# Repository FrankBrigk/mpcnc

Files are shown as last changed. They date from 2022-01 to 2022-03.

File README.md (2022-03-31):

# mpcnc
Dokumentation &amp; Austausch zum Communityprojekt MPCNC

## Bau einer Mostly Printed CNC

**Source**: [v1engineering.com](https://www.v1engineering.com)

**Mod**: Bauraum (X|Y|Z): 980 x 1500 x 81 mm

**Steuerung**: Estlcam V11 via Laptop

**Wunschkonzert**

- Absaugung
- Steuerboard
- SD-Karten/Wifi-Anbindung
- Spann-/Anschlagraster
- Trucks für X-Achse anpassen (Nut) um den Bauraum der Fräße zu vergrößern?

## Dokumentation Communitytreffen

**Total Working Hours: 166.75 | Pizzas: 35.5 | Slices: 284**

### 2022/03/29

**Facts**

Participants: 5  | Hours: 4.5  | Pizzas: 4

**TOPs**

- ~~Pizza~~

**ToDos**

- ~~Absaugung besprechen~~
- ~~Lochraster besprechen~~
- ~~Motorsteuerung~~
- ~~Tastplatte~~ eingerichtet
- ~~Notaus besprechen~~
- ~~Feintuning~~ Belts nachgebessert, Schrittverluste überprüft
- ~~Testfräsungen~~ erfolgreich in Styrodur gefräst

**Zum nächsten Termin**

### 2022/03/22

**Facts**

Participants: 5  | Hours: 3  | Pizzas: 4

**TOPs**

- ~~Pizza~~

**ToDos**

- ~~Z-Achse ansteuern~~
- ~~Testzeichnungen~~
- **~~Testfräsungen!!!!~~**

**Zum nächsten Termin**

### 2022/03/15

**Facts**

Participants: 3  | Hours: 3.5  | Pizzas: 2

**TOPs**

- ~~Pizza~~

**ToDos**

- ~~Drag Chain Halterungen nachbessern~~
- ~~Drag Chains und Halterungen installieren~~
- ~~Z-Achse anschließen~~

**Zum nächsten Termin**

### 2022/03/08

**Facts**

Participants: 5  | Hours: 4  | Pizzas: 5

**TOPs**

- ~~Pizza~~

**ToDos**

- ~~Einzug der Kabel~~
- ~~Drag Chain Halterungen planen und konstruieren~~
- ~~defekten Stepper-Driver tauschen~~
- ~~Probefahrt!~~

**Zum nächsten Termin**

### 2022/02/22

**Facts**

Participants: 4   | Hours: 4  | Pizzas: 3

**TOPs**

- ~~Pizza~~

**ToDos**

- ~~Ausrichtung X/Y diskutieren~~ bleibt wie bestehen wg. Einsehbarkeit Fräsfläche
- ~~Planung der Kabelführung~~
- Einzug der Kabel
- defekten Stepper-Driver tauschen
- ~~defekten Schlitten tauschen~~
- ~~Gt2 Belts einziehen~~
- ~~Mid-Span Supports einbauen~~
- ~~Schleppkette~~

**Zum nächsten Termin**

- Drag Chain (bestellt)

### 2022/02/15

**Facts**

Participants: 4   | Hours: 4  | Pizzas: 3

**TOPs**

- ~~Pizza~~

**ToDos**

- ~~Y-Adapter anfertigen~~
- ~~Werkzeug Halterung fertig verschrauben~~
- ~~Z Achse fertig montieren~~
- ~~rechtwinklig ausrichten~~

**Zum nächsten Termin**

- Planung der Kabelführung
- Gt2 Belts einziehen

### 2022/02/08

**Facts**

Participants: 3   | Hours:  3.5  | Pizzas: 2

**TOPs**

- Pizza

**ToDos**

- ~~Rohr Konstruktion fixieren~~
- ~~Achsen mobtieren~~
- ~~Beginn Z Achse Montage ~~
- ~~Elektronik verdrahten~~

**Zum nächsten Termin**

- Y-Adapter anfertigen
- Werkzeug Halterung fertig verschrauben
- Z Achse fertig montieren
- Planung der Kabelführung
- Gt2 Belts einziehen

### 2022/02/01

**Facts**

Participants: 7  | Hours: 3.5   | Pizzas: 6.5

**TOPs**

- ~~Pizza~~

**ToDos**

- ~~Päckchen auspacken~~
- ~~Montage fortsetzen~~
- ~~Opferplatte montieren~~
- ~~Z-Core fertig montieren~~
- ~~Gehäuse für Elektronik herstellen~~
- Y-Adapter anfertigen
- Elektronik verdrahten

**Zum nächsten Termin**

- fehlende Schrauben kaufen
- Eurokisten für Zubehör

### 2022/01/25

**Facts**

Participants: 6  | Hours: 3.5  | Pizzas: 5

**TOPs**

- ~~Pizza~~
- ~~Crimpzange prüfen und Dupontstecker bestellen ~~
- ~~Drag Chains? Make vs. buy~~ werden bei Bedarf selbst gedruckt
- ~~Mid rail supports?~~ dann
- ~~Hour & Pizza Count~~

**ToDos**

- ~~Workbench aufbauen~~
- ~~Rohre für Z-Achse kürzen~~
- ~~Montage Schlitten und Fräserhalterung~~
- ~~Roadmap/Milestones festlegen~~

**Zum nächsten Termin**

### 2022/01/18

**Facts**

Participants: 5 | Hours: 2.5 | Pizzas: 5

**TOPs**

Pizza
- ~~Druck in .3 Schichtdicke~~ abgelehnt wegen Konflikt Schichtdicken Prusa MK3S & Mini
- ~~Handling Github~~
- ~~kritisch: gewählte Z-Achsenlänge von 150mm~~ auf 81 mm Z-Zustellung geeinigt
- ~~Railsupports~~ werden nach Inbetriebnahme nach Bedarf erstellt
- ~~Kommunikationskanal~~ Gruppe im Messengerdienst Signal
- ~~Slicing & Druckaufteilung~~ gemäß Tabelle im Readme unter Druckdateien

**ToDos**

- ~~Unboxing~~
- Workbench aufbauen
- Elektronik testen
- Roadmap/Milestones festlegen

**Zum nächsten Termin**

- Tischplatte
- Styrodur

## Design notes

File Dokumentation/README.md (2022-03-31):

Die Dokumentationskaptiel wurden zunächst aus dem Standard Arc42 übernommen und müssen noch diskutiert werden. https://www.arc42.de/

**Inhaltsverzeichnis**

- [Einführung und Ziele](#einführung-und-ziele)
- [Randbedingungen](#randbedingungen)
- [Kontextabgrenzung](#kontextabgrenzung)
- [Lösungsstrategie](#lösungsstrategie)
  - [Bauraum](#bauraum)
- [Bausteinsicht](#bausteinsicht)
  - [Level 1 MPCNC](#level-1-mpcnc)
    - [Estlcam](#estlcam)
    - [Motoren](#motoren)
    - [Endschalter](#endschalter)
    - [Tastplatte](#tastplatte)
    - [Steuerung](#steuerung)
  - [Level 2 Steuerung](#level-2-steuerung)
  - [Level 3 CNC Shield](#level-3-cnc-shield)
    - [Pinout](#pinout)
- [Laufzeitsicht](#laufzeitsicht)
- [Verteilungssicht](#verteilungssicht)
- [Querschnittliche Konzepte](#querschnittliche-konzepte)
- [Entscheidungen](#entscheidungen)
  - [Endstops](#endstops)
  - [Ändern der Trucks](#ändern-der-trucks)
- [Qualitätsanforderungen](#qualitätsanforderungen)
  - [Frästoleranz](#frästoleranz)
  - [Mögliche Materialbearbeitung](#mögliche-materialbearbeitung)
- [Risiken](#risiken)
  - [Bauraumgröße](#bauraumgröße)
  - [Arduino Shield](#arduino-shield)
- [Glossar](#glossar)

# Einführung und Ziele
# Randbedingungen

# Kontextabgrenzung
# Lösungsstrategie

## Bauraum
Geplanter Baumraum: (X|Y|Z): 980 x 1500 x 81 mm
Tatsächlicher Baumraum: (X|Y|Z): ? x ? x ? mm

# Bausteinsicht

## Level 1 MPCNC

Die Komponentenübersicht zeigt alle im Kontext der MPCNC genutzen Komponenten und deren Schnittstellen. 

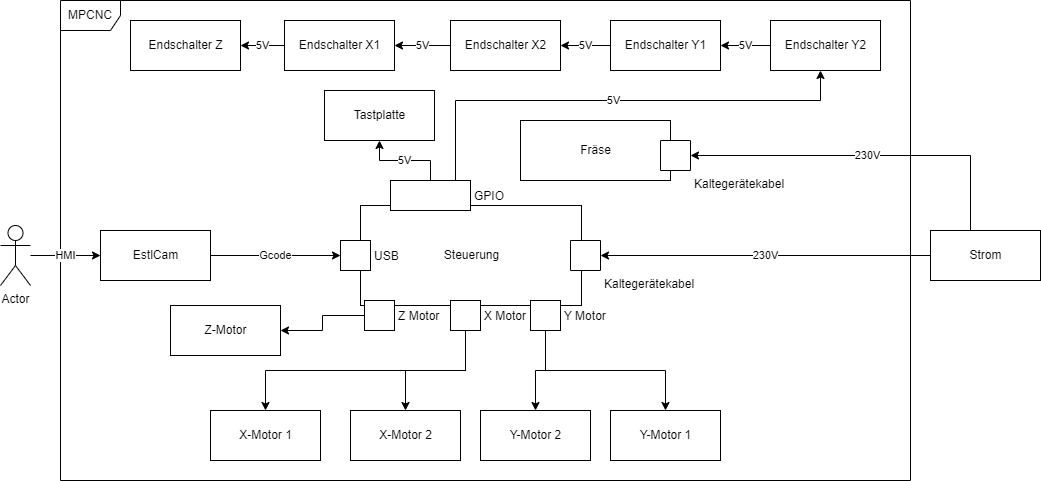
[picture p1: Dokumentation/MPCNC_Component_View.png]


### Estlcam
Estlcam wird in der Version 11 verwendet

### Motoren
Es werden Nema 17 Motoren verwendet.

### Endschalter
Die Endschalter sind öffner und werden in reihe geschalten. 

### Tastplatte
Maße: 

### Steuerung

## Level 2 Steuerung

## Level 3 CNC Shield

### Pinout

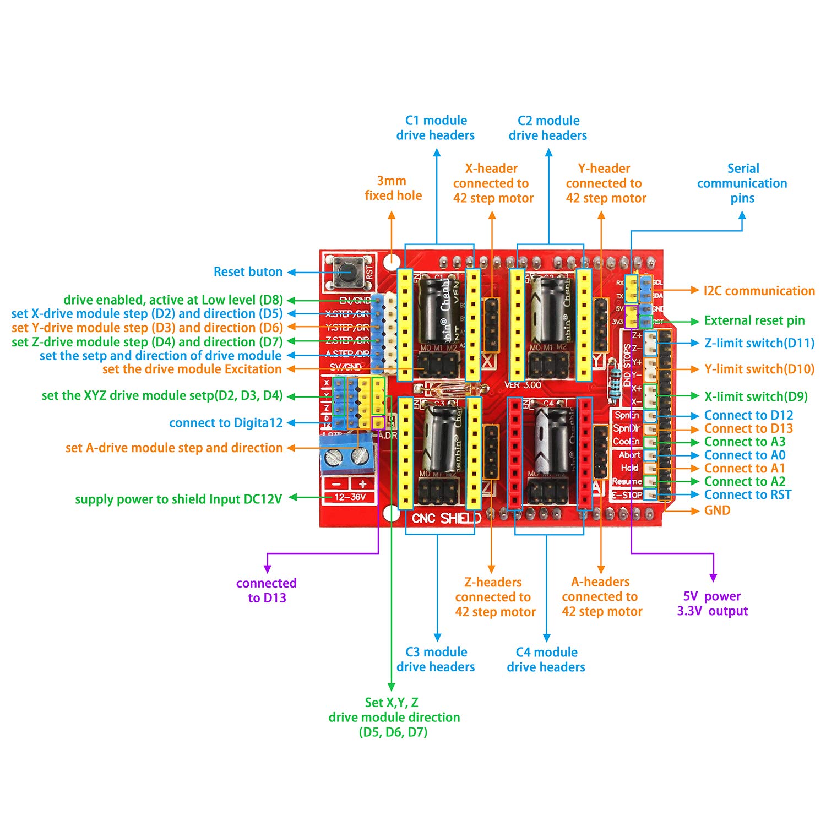
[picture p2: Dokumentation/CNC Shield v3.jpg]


# Laufzeitsicht
# Verteilungssicht
# Querschnittliche Konzepte

# Entscheidungen

## Endstops
Endstops als öffner hat den Vorteil, dass Kabelbrüche erkannt werden können, da in diesen Fall die Schalter immer als Ausgelöst erkannt werden. 

Die Reihenschaltung ist möglich, da Estlcam bei der Referenzfahrt in folgender Sequenz vorgeht:
 
- Einlernen der Z-Achse 
- Einlernen der X-Achse
- Einlernen der Y-Achse

Das Einlernen beinhaltet das Verfahren der Achse bis zum Endanschlag, anschließendes reversieren um einen konfigurierbaren Weg, nochmals Verfahren bis zur Achse und ein erneutes reversieren.

Das zweite Verfahren ist eine genaue Messfahrt um den Endanschlag so genau wie möglich zu ermitteln um anhand der vorherigen Messung Pulsverluste zu ermitteln.

## Ändern der Trucks
Die Trucks für die X-Achse werden anders als von der Dokumentation montiert, damit die Fräse vom Kontrollplatz aus verfolgt und so schnell wie möglich reagiert werden kann.

Durch das Ändern entsteht jedoch eine Abweichung des geplanten Bauraums. Dieser Unterschied entsteht, da der Core nicht in die Nut der Trucks fahren kann.

# Qualitätsanforderungen
## Frästoleranz
## Mögliche Materialbearbeitung

# Risiken

## Bauraumgröße

## Arduino Shield

# Glossar

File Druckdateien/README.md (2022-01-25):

# Druckerteile

# Primo Printed Parts List

QTY |	Part Name	| Infill	| Color | Sliced | In Charge | done
--- |   ---- | ---- | ---- | --- | --- | --- 
2 |	Corner Bottom |	45%+	| B | Set3 | Max | 2/2
2 |	Corner Bottom Mirrored |	45%+ |	B | Set3 | Max | 2/2
2 |	Corner Top |	45%+ |	A | Set4| Max | 2/2
2 |	Corner Top Mirrored |	45%+ |A | Set4 | Max | 2/2
2 |	Lower Belt |	45%+ |	A | Set2| markus | 2/2
2 |	Lower Belt Mirrored |	45%+ |	A | Set2| markus | 2/2
2 |	Upper Belt |	45%+ |	B | Set3| Max | 2/2
2 |	Upper Belt Mirrored |	45%+ |	B | Set3| Max | 2/2
4 |	Corner Leg Lock |	45%+ |	B | Set3| Max | 4/4
4 |	Feet |	45%+ |	A | Set4| Max | 4/4
2 |	Wire Darryl |	45%+ |	A | Set4| Max | 2/2
4 |	Stop Block (Dual only) |	45%+ |	A | Set4| Max | 4/4
<b>Trucks   </b>
2 |	Truck |	45%+ |	A | Set2| markus | 2/2
2 |	Truck Mirrored |	45%+ |	A | Set2| markus | 2/2
4 |	Truck Clamp |	45%+ |	B | Set3| Max | 4/4
<b>Z-Axis  </b>
1 |	Z Motor |	45%+ |	A | Set6| markus | 1/1
1 |	Z Coupler |	45%+ |	A | Set6| markus | 1/1
2 |	Nut Trap |	45%+ |	A | Set5| markus | 2/2
1 |	Upper Tool Plate |	45%+ |	A | Set4| Max | 1/1
1 |	Lower Tool Plate |	45%+ |	A | Set4| Max | 1/1
<b>Center Assembly	</b>	
2 |	Core Z Clamp 1 |	45%+ |	A | Set2| markus | 2/2
2 |	Core Z Clamp 2 |	45%+ |	A | Set2| markus | 2/2
3 |	Core Clamp |	45%+ |	A | Set5| markus | 3/3
1 |	Core ClampY |	45%+ |	A | Set5| markus| 1/1
1 |	Core |	70% |	B | Set1 | Max | 1/1

Color A = Schwarz
Color B = Orange

## STL
Heruntergeladene Bauteilmodelle von Thingiverse: https://www.thingiverse.com/thing:4550789

## .3fm
Prusa Slicer Projekt, um Druckeigenschaften anzupassen und/oder Teile neu zu gruppieren.

## .gcode
Geslicte Dateien, welche der 3D-Drucker zum Drucken der Teile benötigt.

# Filamentbedarf
## Orange
<p> Set1 = 426,15 g
<p> Set3 = 426,88 g
<p> <b>Summe = 853,03 g </b>

## Schwarz
<p> Set2 = 558,57 g
<p> Set4 = 444,03 g
<p> Set5 = 96,77 g
<p> Set6 = 81,32 g
<p> <b>Summe = 1180,69 g </b>
  
  ## Filamentbestellung (durch Max)
2x 800g orange
3x 800g schwarz

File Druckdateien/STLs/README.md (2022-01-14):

# Primo Printed Parts List
QTY |	Part Name	| Infill	| Color | Sliced
--- |   ---- | ----| ---- | ---
2 |	Corner Bottom |	45%+	| B | Set3
2 |	Corner Bottom Mirrored |	45%+ |	B | Set3
2 |	Corner Top |	45%+ |	A | Set4
2 |	Corner Top Mirrored |	45%+ |A | Set4
2 |	Lower Belt |	45%+ |	A | Set2
2 |	Lower Belt Mirrored |	45%+ |	A | Set2
2 |	Upper Belt |	45%+ |	B | Set3
2 |	Upper Belt Mirrored |	45%+ |	B | Set3
4 |	Corner Leg Lock |	45%+ |	B | Set3
4 |	Feet |	45%+ |	A | Set4
2 |	Wire Darryl |	45%+ |	A | Set4
4 |	Stop Block (Dual only) |	45%+ |	A | Set4
<b>Trucks   </b>
2 |	Truck |	45%+ |	A | Set2
2 |	Truck Mirrored |	45%+ |	A | Set2
4 |	Truck Clamp |	45%+ |	B | Set3
<b>Z-Axis  </b>
1 |	Z Motor |	45%+ |	A | Set6
1 |	Z Coupler |	45%+ |	A | Set6
2 |	Nut Trap |	45%+ |	A | Set5
1 |	Upper Tool Plate |	45%+ |	A | Set4
1 |	Lower Tool Plate |	45%+ |	A | Set4
<b>Center Assembly	</b>	
2 |	Core Z Clamp 1 |	45%+ |	A | Set2
2 |	Core Z Clamp 2 |	45%+ |	A | Set2
3 |	Core Clamp |	45%+ |	A | Set5
1 |	Core ClampY |	45%+ |	A | Set5
1 |	Core |	70% |	B | Set1

Color A = Schwarz
Color B = Orange

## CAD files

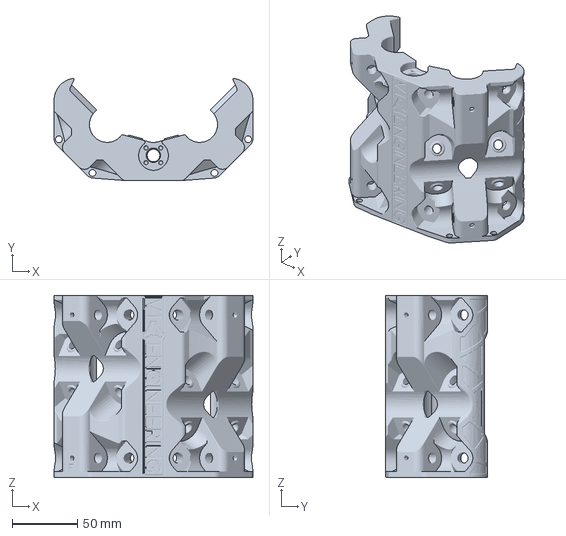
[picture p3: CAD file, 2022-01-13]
Druckdateien/.3mf/Orange/Set1.3mf
152.9 x 78.5 x 140.0 mm

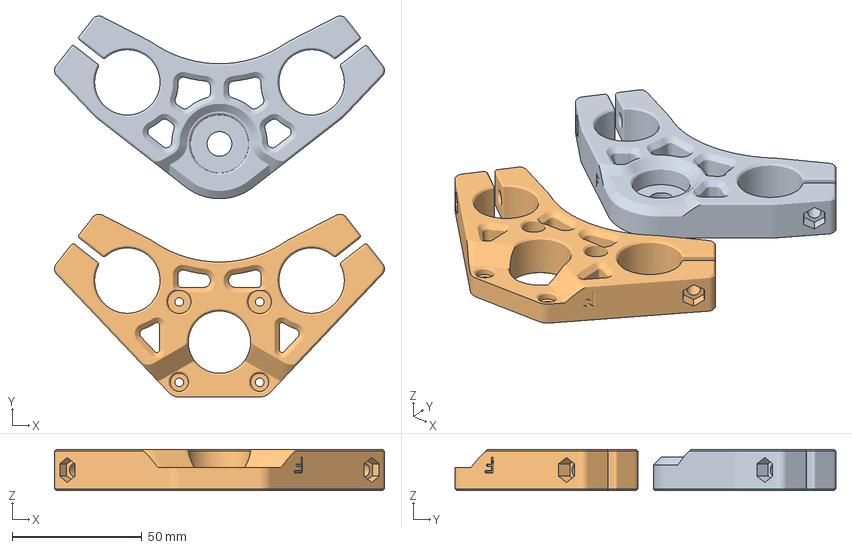
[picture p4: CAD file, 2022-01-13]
Druckdateien/.3mf/Schwarz/Set6.3mf
127.3 x 146.9 x 16.0 mm
Z_Coupler_F_Primo.STL
Z_Motor_F_Primo.STL

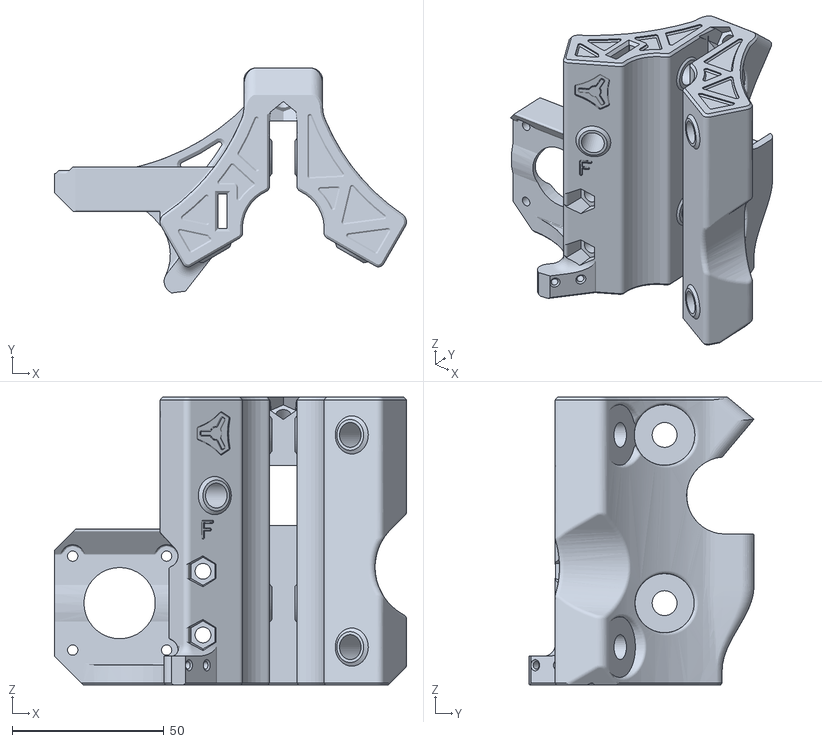
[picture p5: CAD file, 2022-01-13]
Druckdateien/STLs/Truck_F_Primo_V1.STL
116.2 x 74.2 x 95.0

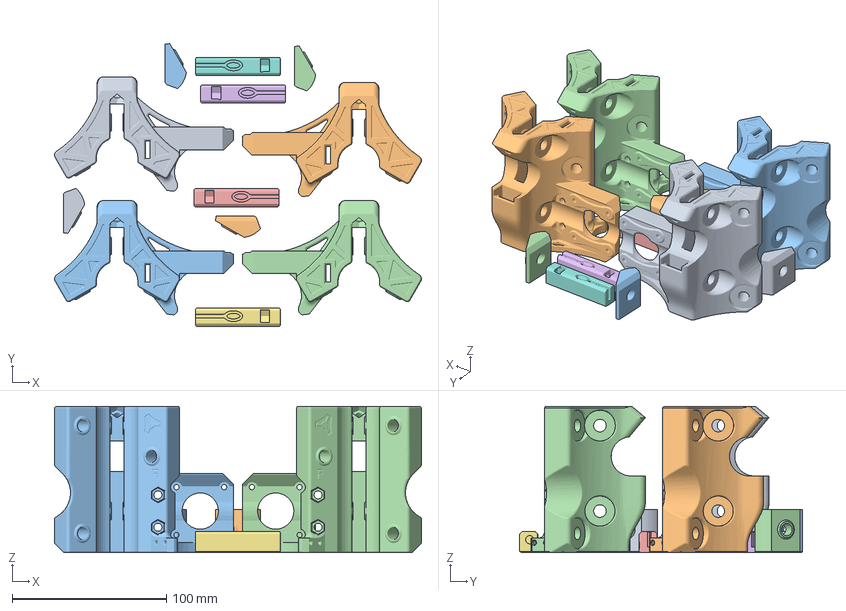
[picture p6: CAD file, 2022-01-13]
Druckdateien/.3mf/Schwarz/Set2.3mf
238.3 x 183.6 x 95.0 mm
Truck_F_Primo_Mirrored_V1.stl x 2
Truck_F_Primo_V1.STL x 2
Lower_Belt_F_Primo.STL x 2
Lower_Belt_F_Primo_Mirrored.stl x 2
Core_Z_Clamp_1_F_V1.STL x 2
Core_Z_Clamp_2_F_V1.STL x 2

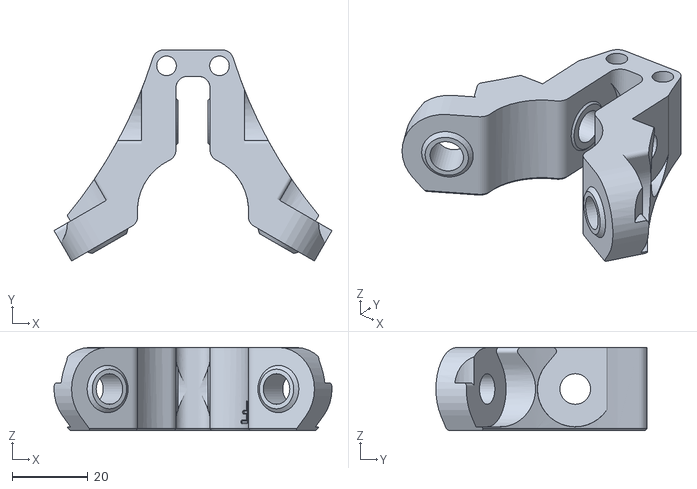
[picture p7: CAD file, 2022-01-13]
Druckdateien/STLs/Core_Clamp_F_Primo_V1.STL
73.6 x 55.9 x 22.0

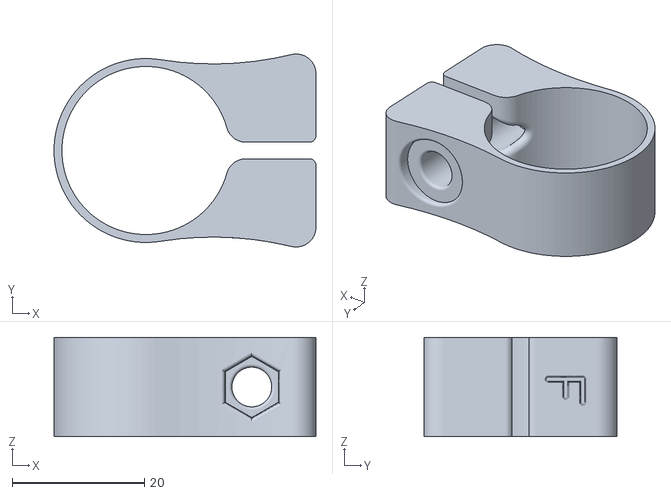
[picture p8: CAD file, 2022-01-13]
Druckdateien/STLs/Stop_Block_25.STL
39.6 x 29.2 x 15.0

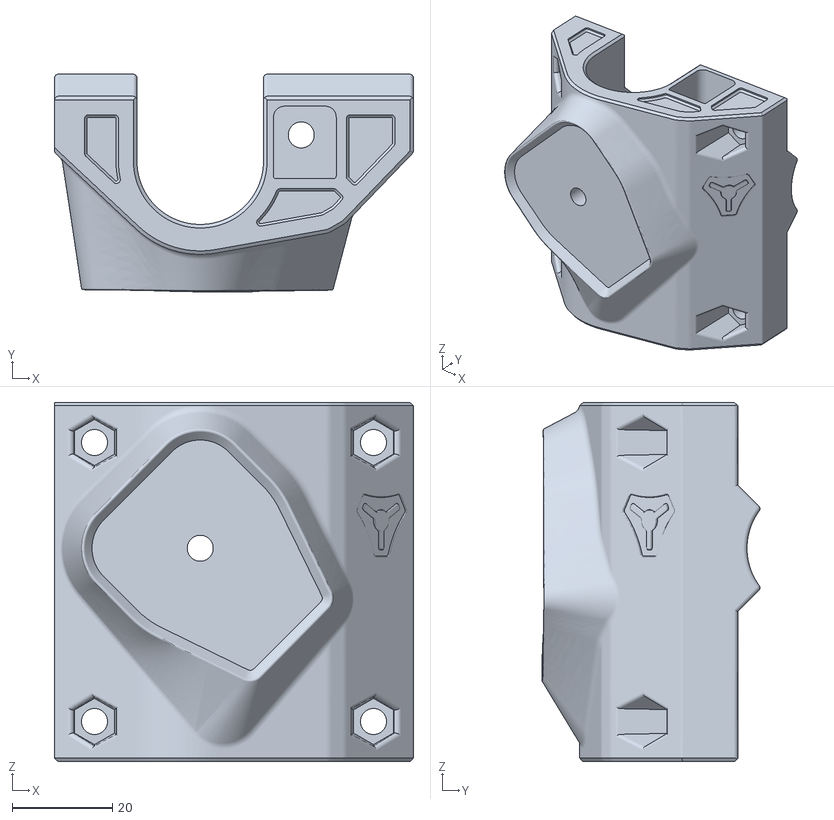
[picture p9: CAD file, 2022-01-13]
Druckdateien/STLs/Corner_Bottom_F_Primo_Mirrored.stl
71.8 x 43.6 x 71.8

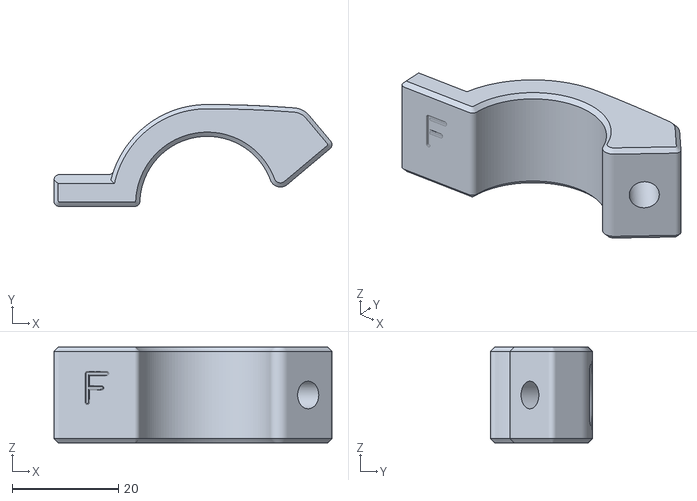
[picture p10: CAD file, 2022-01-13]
Druckdateien/STLs/Truck_Clamp_F_Primo.STL
52.4 x 19.2 x 18.0

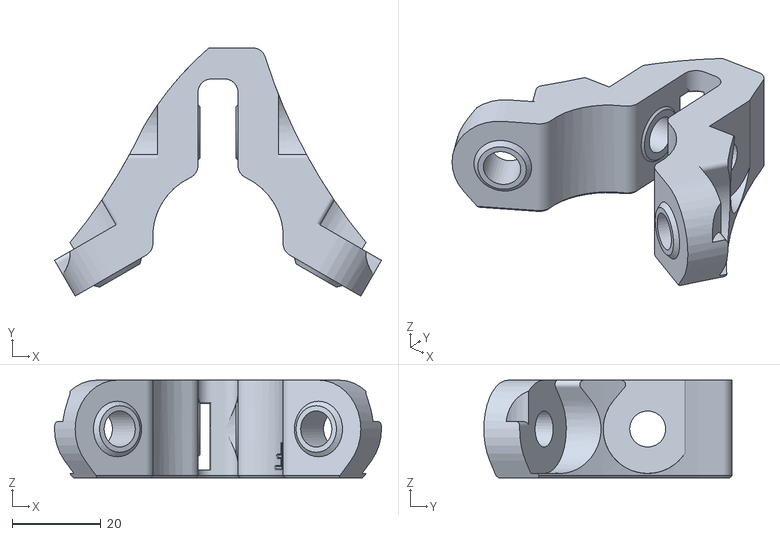
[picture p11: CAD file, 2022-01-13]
Druckdateien/STLs/Core_Clamp_Y_F_Primo_V1.STL
73.6 x 55.9 x 22.0

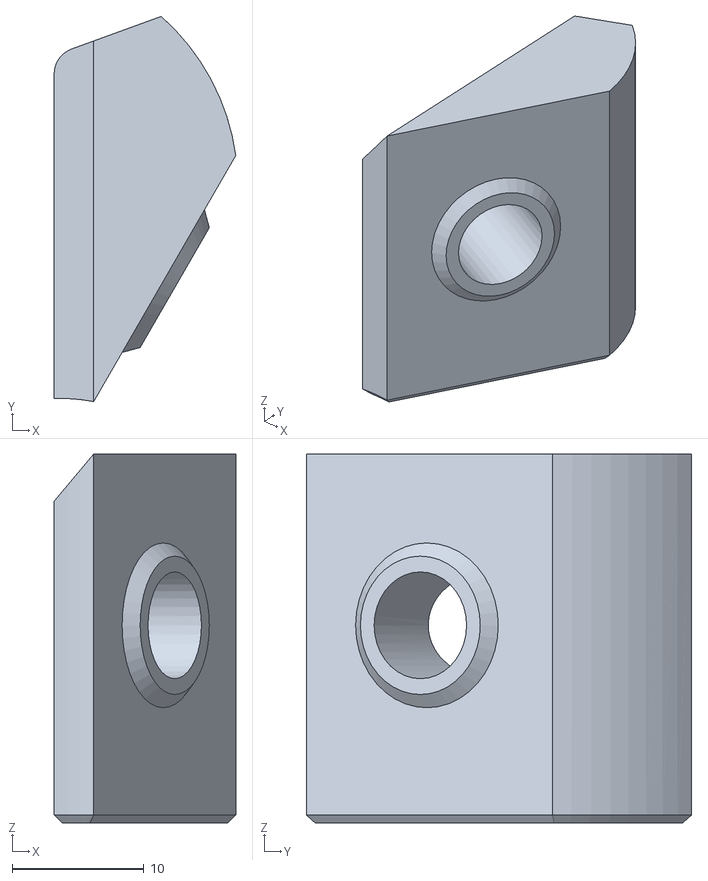
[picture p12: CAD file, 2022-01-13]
Druckdateien/STLs/Core_Z_Clamp_1_F_V1.STL
13.8 x 29.2 x 28.0

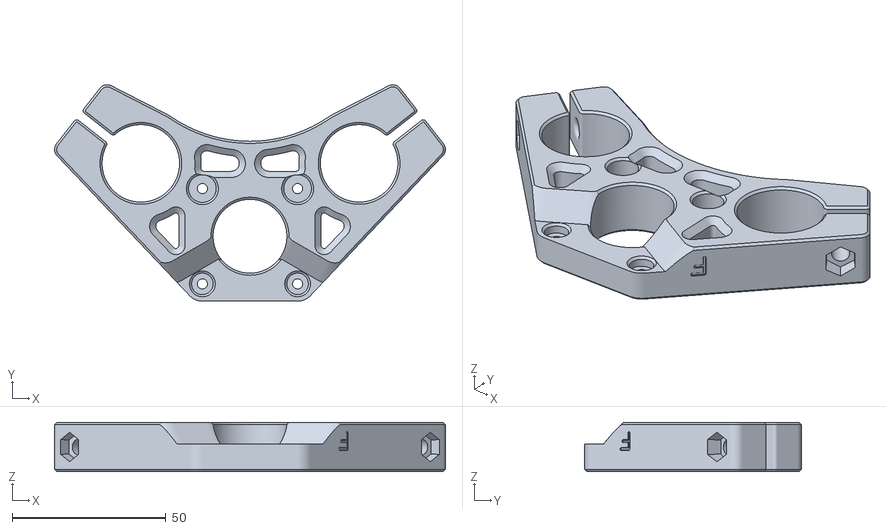
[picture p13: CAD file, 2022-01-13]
Druckdateien/STLs/Z_Motor_F_Primo.STL
127.3 x 70.5 x 16.0

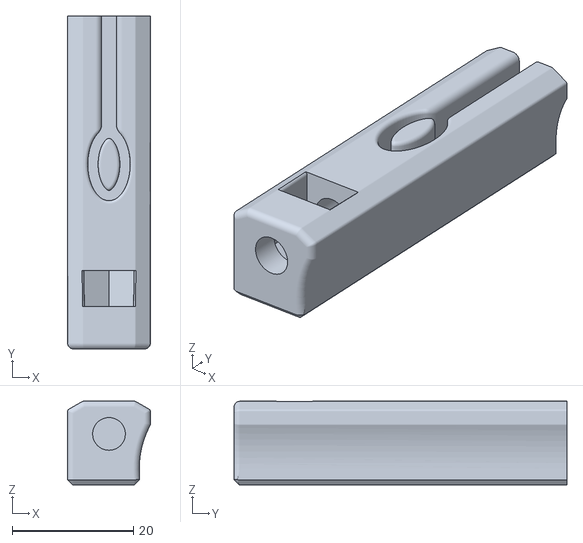
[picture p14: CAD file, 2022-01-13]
Druckdateien/STLs/Upper_Belt_F_Primo.STL
13.7 x 55.0 x 13.8

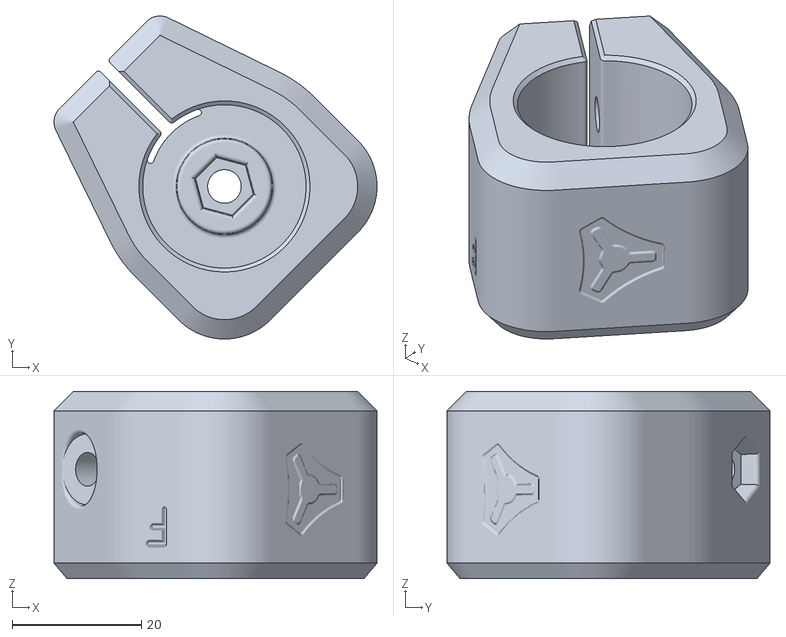
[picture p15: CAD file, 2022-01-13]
Druckdateien/STLs/Corner_Leg_Lock_F_Primo.STL
50.1 x 50.1 x 29.0

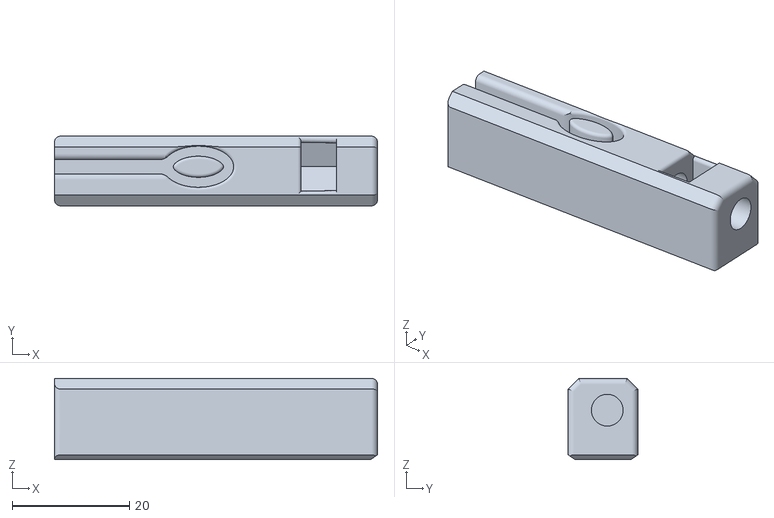
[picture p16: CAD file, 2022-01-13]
Druckdateien/STLs/Lower_Belt_F_Primo_Mirrored.stl
55.0 x 11.8 x 13.8

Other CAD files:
Druckdateien/STLs/Corner_Bottom_F_Primo.STL
Druckdateien/STLs/Core_Z_Clamp_2_F_V1.STL
Druckdateien/STLs/Lower_Belt_F_Primo.STL
Druckdateien/STLs/Wire_Darryl.STL
Druckdateien/STLs/Lower_Tool_Plate_F_Primo.STL
Druckdateien/STLs/Truck_F_Primo_Mirrored_V1.stl
Druckdateien/STLs/Upper_Belt_F_Primo_Mirrored.stl
Druckdateien/STLs/Upper_Tool_Plate_F_Primo.STL
Druckdateien/STLs/Z_Coupler_F_Primo.STL

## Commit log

2022-01-13 STL files for MPCNC Primo
    [Core_Clamp_F_Primo_V1.STL, Core_Clamp_Y_F_Primo_V1.STL, Core_Z_Clamp_1_F_V1.STL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]
2022-01-13 Hinzufügen der Druckteile Liste in Docu
2022-01-13 Readme in Stl-Ordner erstellt. Overview datei gelöscht.
2022-01-13 3mf files erstellt und README
    [Set1.3mf, Set2.3mf, Set6.3mf]
2022-01-13 Erstellen und zippen von gcode files
    In Github können max 100MB auf dem normalen Weg hochgeladen werden. Ansonsten muss LFS verwendet werden.
2022-01-14 Berechnung des notwendigen Filaments
2022-01-14 Filamentbedarf unter Druckerteile Doku
2022-01-14 Filamentbedarf von STL Doku entfernt
2022-03-30 Update Dokumentation
    - Wunschkonzert -> X-Achsen Trucks anpassen
    - Dokumentation des Aufbaus in Dokumentationsordner
2022-03-31 Update Dokumentation
    - Upload von CNC Shield Outputs
    - Erste Komponentenbeschreibung
    - Estlcam
    - Motoren
    - Endschalter
    - Tastplatte
    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
2022-03-31 Entfernen der Dokumentationsüberschrift
2022-04-06 Add files via upload
    Dokumentation erste Schritte Inbetriebnahme und Doku der Elektronik und der Verdrahtung
